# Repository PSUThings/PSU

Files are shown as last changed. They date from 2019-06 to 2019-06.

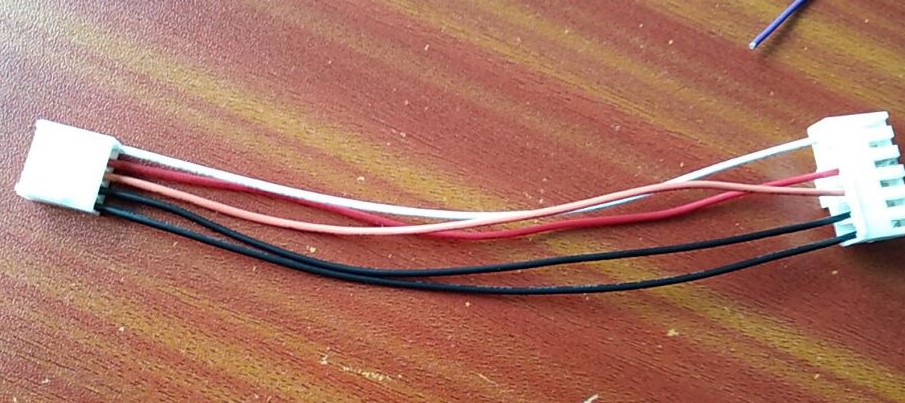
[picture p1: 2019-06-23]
Saturn/DesignFiles/TopMountCable.jpg

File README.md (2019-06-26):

Both designs work without issue on my end, BOM and Gerbers are there along with Eagle files.  
I have included as much info as i think you will need to get one of these up and running without issue.   
The rear adapters are stl files ready for 3d printing, the original design files i couldnt find, but shouldnt be needed.  
No licence, do what you want with the files.   

As suggested by someone, here is the links to oshpark. These should be easier for people who have no idea how to get a pcb made but can solder well. 

DreamPSU
https://oshpark.com/shared_projects/REVINxcE

SaturnPSU
https://oshpark.com/shared_projects/gURypobA

<!-- Now i have that out the way. Here is a little rant for you that checked this file. This shit is what represents just under 2 years of my life, I loved making the Dreamcast version of the psu cause it was new, fun and interesting, i learned so much from doing this, from eagle stuff to taking a labor of love to production and seeing peoples feedback. But the saturn version? I dont think there was one part of the experience that i enjoyed. Which sucks, i really wanted to do the saturn version cause of peoples constant asking for it, emails, tweets, facebook messages, all the time, so i was totally down to do it. But my god what a fucking shit show its turned out to be. From the mess that is saturn revisions to the fucking absolute disgrace that was the indiegogo campaign. There are god knows how many saturn revisions, which i had to try and source hardware for, which by the way is not an easy feat when your relying on ebay pictures to try and work out if you already own that version of the console, let alone the price of those things, most of which i brought non working or "untested", they cost me between £20-30 each, and i have no use for them after the final design was done. I dont play the saturn and when i did play it as a kid i wasnt a fan of it to be honest. My love was always the PS1 and the dreamcast. The fuck fest that happened with the campaign was nothing but a nightmare, from the first time the manafacturer screwed me over by increasing a quote by almost 30%, to issues with the cabling design for the top doown saturns and chinas inability to follow basic instructions, to the issues with fake or cloned TI chips. i couldnt beleive it. When i was oriignaly considering the saturn and wether or not i should go ahead and do a campaign for it (which by the way i had to, i know people are like "well what about the money you made from the dreampsu campaign", that dreampsu campaign left me damn near 2k in debt. so there was no money to put towards the saturn stuff besides a few intiial prototypes) i never would have dreamed it would turn out the way it did. I let myself down, everyone who help with the campaign down and everyone who made an order elsewhere down. That shit is not easy to handle when your as mentally fucked as i am lmao. And if your wondering, i dont care if i come across as weird or fucked up here, im drunk and im tired and pissed off, let me rant. Talking of ranting, its SOOOO hard to be nice to people all the time when they are berating you and trying to make you feel like shit (which btw guys, good luck cause i already feel as shit as its humanily possible), I do not envy people in customer service jobs.  OK im probably gonna leave this now before i start rambling, but i will say this, to anyone who has a neat idea or something that will help out the retro community, run at it with full force, make it the best thing you can possibly make it and then for the love of god dont try to sell it to anyone. Release that shit open source and never have to go though the same shit i have with this. I do want to say, once again to everyone that backed this thing, i am sorry from the bottom of my heart, this shit rips me apart every damn day knowing that you guys didnt get what u wanted. Hell i fear checking my phone or emails anytime it makes a noise though fear i have to face one of you again. I would also like to say thank you to everyone that was understanding of the sitation, everyone who offered help or guidance and advice, i cannot thank you enough, i dont want to mention people by names cause that aint fair, but you know who you are, even i replied to your email with not very much in the way of words, or didnt reply at all, i read every single email and bit of adcive you sent and i thank you for that.   Thats it from be folks, If at any point i decide to do another PSU for another console, i wont be selling them in any way shape or form, but i will make the files avaible for people as a further apology to everyone for all that has happened.  -->

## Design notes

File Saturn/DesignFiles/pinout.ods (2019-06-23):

Type A | GND | GND | 3.3V | 5v |  | 9v | TOP MOUNTED
Type B | GND | GND | 3.3V | 5v | 9v
Type C-5 | GND | GND | 5v | 5v | 12v
Type C-4 | GND | GND | 5v | 5v

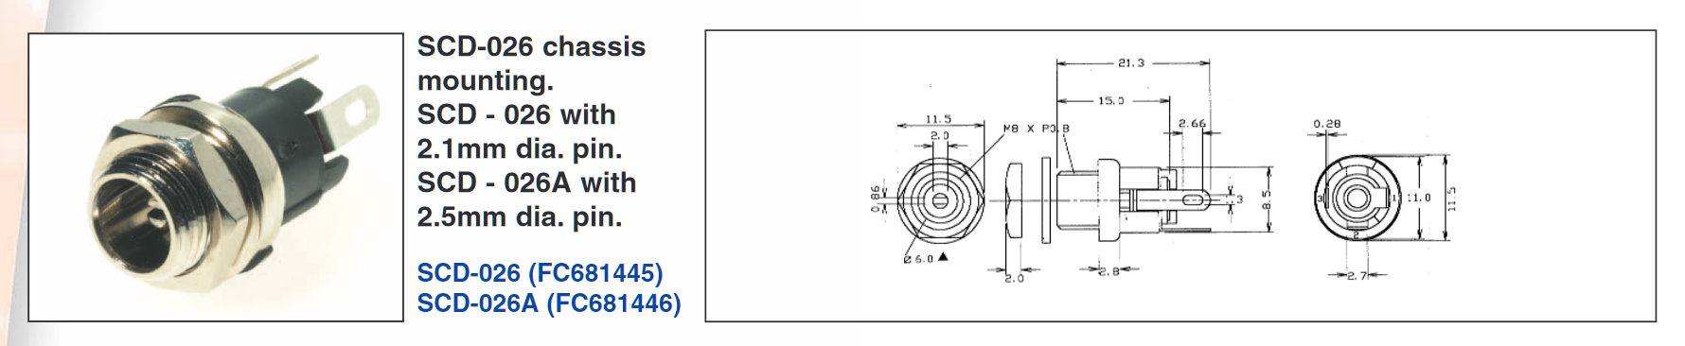
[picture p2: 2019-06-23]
Saturn/DesignFiles/Rear2.5MMJack - FC681446.png

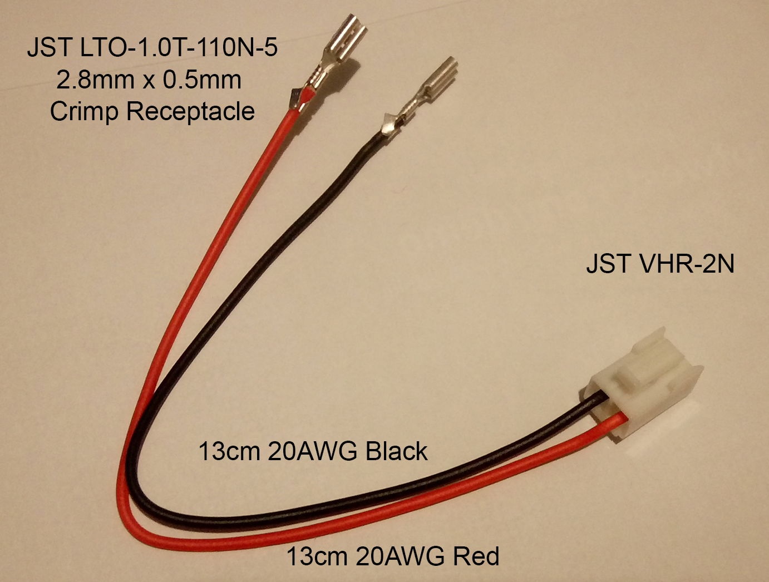
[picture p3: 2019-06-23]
Saturn/DesignFiles/Cable1.jpg

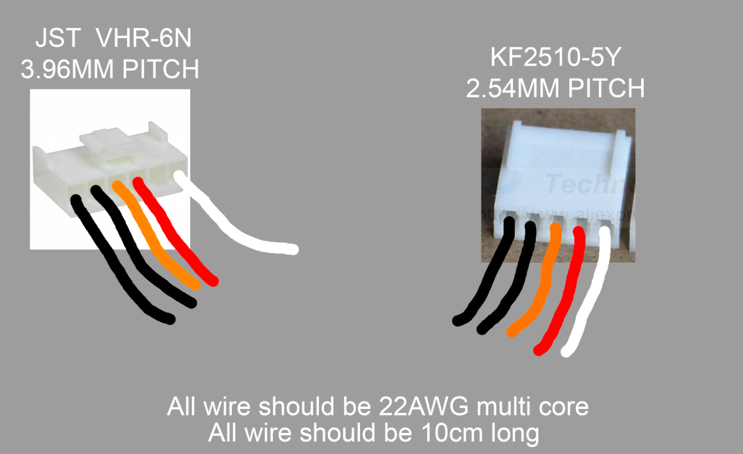
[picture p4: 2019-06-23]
Saturn/DesignFiles/xNnVytZ.png

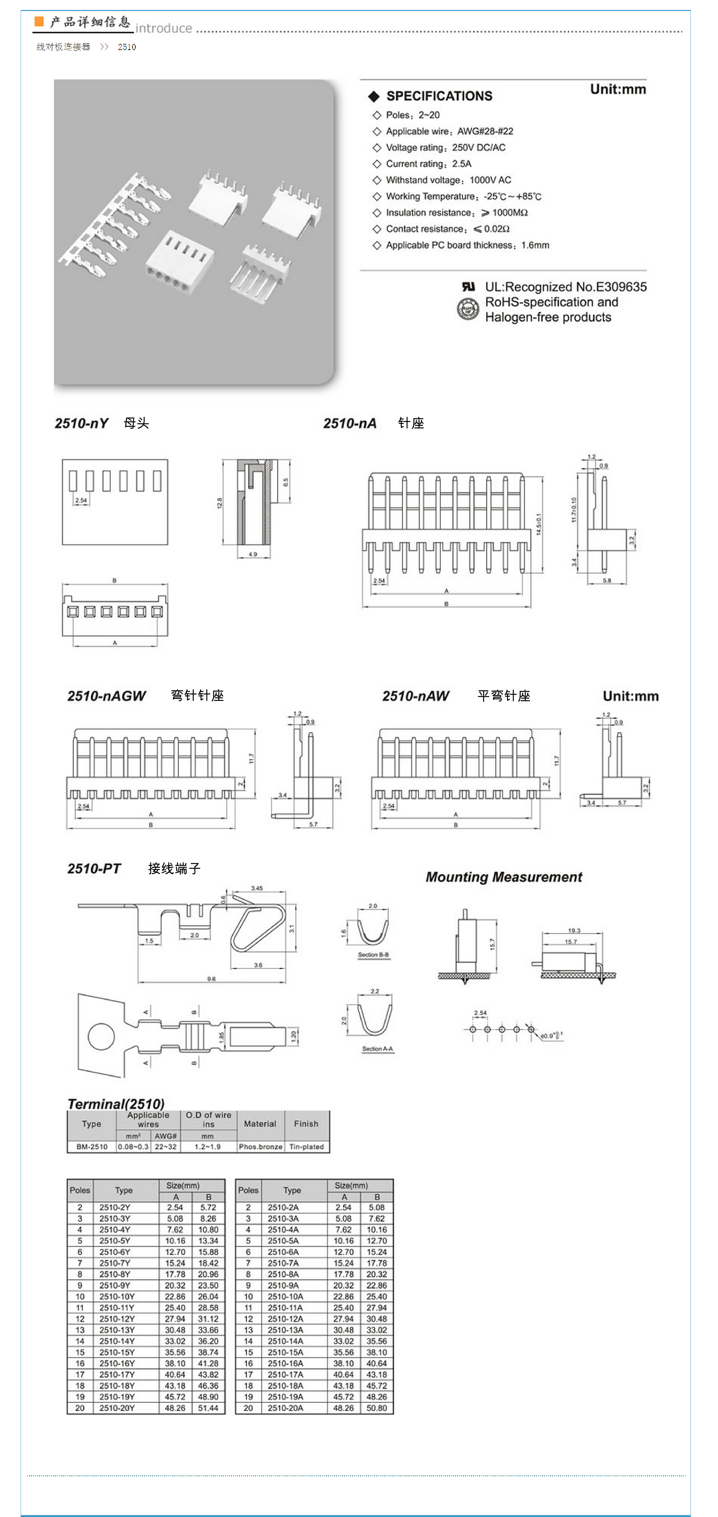
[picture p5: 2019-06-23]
Saturn/DesignFiles/KF2510-16A-2-54MM_C48201.png

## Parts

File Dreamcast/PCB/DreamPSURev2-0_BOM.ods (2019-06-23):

Ref | Value | Technology | Footprint | Manufacture | Manufacture Part Number | Quantity
R1,R6 | 10.2k,1%,1/10w | SMD | 0603 | Yageo | RC0603FR-0710K2L | 2
R4,R8 | 22.1k,1%,1/10w | SMD | 0603 | Yageo | RC0603FR-0722K1L | 2
R6 | 73.2k,1%,1/10w | SMD | 0603 | Yageo | RC0603FR-0773K2L | 1
R3,R7 | 100KΩ (1003) ±1% | SMD | 0603 | Yageo | 0603WAF1003T5E | 2
R2 | 124k,1%,1/10w | SMD | 0603 | Yageo | RC0603FR-07124KL | 1
C10,C2 | 100nF (104) ±10% 50V | SMD | 0603 | Yageo | CC0603KRX7R9BB104 | 2
C16,C8 | 1uF (105) ±10% 50V | SMD | 0603 | MuRata | CL10A105KB8NNNC | 2
C17,C9 | CAP CER 8200PF 50V X7R | SMD | 0603 | MuRata | GRM188R71H822KA01D | 2
C11,C3 | 10pF (100) ±5% 50V | SMD | 0603 | Kemet | CL10C100JB8NNNC | 2
C4,C5,C12,C13 | 10uF (106) ±10% 50V | SMD | 1206 | MuRata | CL31A106KBHNNNE | 4
C14,C15,C6,C7,C1 | 22uF (226) ±20% 25V | SMD | 0805 | Samsung | CL21A226MAQNNNE | 5
L2,L1 | Inductor 2.5uH | SMD | 7.60mm x 6.90mm | Pulse | PA4341.252NLT | 2
U1,U3 | IC REG BUCK ADJ 5.5A | SMD | 14-TSSOP | Texas Instruments | TPS54525PWPR | 2
JP3 | 2 Positions Header Right Angle Connector 3.96mm | THT | 7.92mm x 8.6mm | TE Connectivity | 647676-2 | 1
JP2 | 3 Positions Header Connector 7.92mm | THT | 11.9mm x 8.5mm | TE Connectivity | 1-1123724-2 | 1
JP1 | 6 Position, Bottom Entry Connector 3.96mm | THT | 23.7mm x 11.90mm | Molex | 0009523062 | 1
J1, J2, J3, J4 | 2 Positions Header Connector 2.54mm | THT | 1x2-2.5mm |  | 6030916A 1x2 Male | 4
 | REAR POWER JACK |  |  |  | FC681446 | 1

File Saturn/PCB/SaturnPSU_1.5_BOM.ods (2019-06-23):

Ref | Value | Technology | Footprint | Manufacture | Manufacture Part Number | Quantity
R11,R5 | 10.2k,1%,1/10w | SMD | 0603 | Yageo | RC0603FR-0710K2L | 2
R9 | 22.1k,1%,1/10w | SMD | 0603 | Yageo | RC0603FR-0722K1L | 1
R12 | 100KΩ (1003) ±1% | SMD | 0603 | Yageo | 0603WAF1003T5E | 1
R10 | 124k,1%,1/10w | SMD | 0603 | Yageo | RC0603FR-07124KL | 1
R6 | 33.2k,1%,1/10w | SMD | 0603 | Yageo | RC0603FR-0733K2L | 1
R1 | 54.9k,1%,1/10w | SMD | 0603 | Yageo | RC0603FR-0754K9L | 1
C17 | 47µF ±20% 6.3V 1206 | SMD | 1206 | Samsung Electro-Mechanics | CL31A476MQHNNWE | 1
C2,C16,C23 | 100nF (104) ±10% 50V | SMD | 0603 | Yageo | CC0603KRX7R9BB104 | 3
C1,C21 | 1uF (105) ±10% 50V | SMD | 0603 | MuRata | CL10A105KB8NNNC | 2
C22 | CAP CER 8200PF 50V X7R | SMD | 0603 | MuRata | GRM188R71H822KA01D | 1
C9 | 10pF (100) ±5% 50V | SMD | 0603 | Kemet | CL10C100JB8NNNC | 1
C19,C20 | 10uF (106) ±10% 50V | SMD | 1206 | MuRata | CL31A106KBHNNNE | 2
C10,C15,C18,C24 | 22uF (226) ±20% 25V | SMD | 0805 | Samsung | CL21A226MAQNNNE | 4
L2,L3 | Inductor 2.5uH | SMD | 7.60mm x 6.90mm | Pulse | PA4341.252NLT | 2
U6 | Buck Switching Regulator | SMD | TSOT-23-6 | Texas Instruments | TPS563200 | 1
U2 | IC REG BUCK ADJ 5.5A | SMD | 14-TSSOP | Texas Instruments | TPS54525PWPR | 1
U5 | Linear Voltage Regulator | SMD | SOT-89-3 | STMicroelectronics | L78L09ABUTR | 1
SW1 | Slide Switch SPDT Surface Mount, Right Angle | SMD | 8mmx6mm | C&K | AYZ0102AGRLC | 1
JP5 | 2 Positions Header Right Angle Connector 3.96mm | THT | 7.92mm x 8.6mm | TE Connectivity | 647676-2 | 1
JP4 | 3 Positions Header Connector 7.92mm | THT | 11.9mm x 8.5mm | TE Connectivity | 1-1123724-2 | 1
J5,J6,J7 | 2 Positions Header Connector 2.54mm | THT | 1x2-2.5mm |  | 6030916A 1x2 Male | 3
J1 | 5 Positions Header Connector 2.54mm | THT | 1x5-2.54mm |  | KF2510-5A-2.54MM | 1
JP1 | 5 Position, Bottom Entry Connector 3.96mm | THT | 20.85mm x 11.90mm | Molex | 09-48-4059 | 1
 | REAR POWER JACK |  |  |  | FC681446 | 1

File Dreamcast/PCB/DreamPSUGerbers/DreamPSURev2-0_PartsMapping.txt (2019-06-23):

Partlist

Exported from DreamPSURev2-0.brd at 12/03/2018 16:44

EAGLE Version 8.4.3 Copyright (c) 1988-2017 Autodesk, Inc.

Assembly variant: 

Part     Value                       Package                     Library        Position (mm)         Orientation

C1       22uF                        C0805                       DreamPSURev1-9 (39.9 1.84)           R0
C2       100nF                       C0603                       DreamPSURev1-9 (33.2 21.64)          R270
C3       10pF                        C0603                       DreamPSURev1-9 (37 33.04)            R180
C4       10uF                        C1206                       DreamPSURev1-9 (38.8 26.14)          R270
C5       10uF                        C1206                       DreamPSURev1-9 (36.4 26.14)          R270
C6       22uF                        C0805                       DreamPSURev1-9 (34.7 13.99)          R180
C7       22uF                        C0805                       DreamPSURev1-9 (34.7 16.49)          R180
C8       1uF                         C0603                       DreamPSURev1-9 (30.2 35.74)          R90
C9       8.2nF                       C0603                       DreamPSURev1-9 (32.3 35.74)          R90
C10      100nF                       C0603                       DreamPSURev1-9 (12.509 10.385)       R270
C11      10pF                        C0603                       DreamPSURev1-9 (16.42 21.62)         R180
C12      10uF                        C1206                       DreamPSURev1-9 (18.85 13.9)          R270
C13      10uF                        C1206                       DreamPSURev1-9 (16.28 13.93)         R270
C14      22uF                        C0805                       DreamPSURev1-9 (18.7291 2.9035)      R90
C15      22uF                        C0805                       DreamPSURev1-9 (15.8 2.89)           R90
C16      1uF                         C0603                       DreamPSURev1-9 (9.6 24.54)           R90
C17      8.2nF                       C0603                       DreamPSURev1-9 (11.7 24.54)          R90
J1       5V                          10X02MTA                    DreamPSURev1-9 (44 29)               R90
J2       12V                         10X02MTA                    DreamPSURev1-9 (44 22.5)             R90
J3       5V                          10X02MTA                    DreamPSURev1-9 (44 35.5)             R90
J4       12V                         10X02MTA                    DreamPSURev1-9 (44 16)               R90
JP1      09-48-3064                  09-62-3062                  DreamPSURev1-9 (33.44 8.32)          R0
JP2      DC-PWRSW                    1-1123724-2                 SaturnPSU_1.5  (7.786 35.823)        R180
JP3      640445-2_3.96MM-2PIN-HEADER 640445-2_3.96MM-2PIN-HEADER SaturnPSU_1.5  (19.6 35.94)          R180
L1       2.5uH                       PA4341.252NLT               SaturnPSU_1.5  (28 19.04)            R0
L2       2.5uH                       PA4341.252NLT               SaturnPSU_1.5  (6.5 8.2)             R0
R1       10.2k                       R0603                       DreamPSURev1-9 (27.8 32.44)          R180
R2       124k                        R0603                       DreamPSURev1-9 (37 35.14)            R0
R3       100k                        R0603                       DreamPSURev1-9 (28.1 35.74)          R90
R4       22.1k                       R0603                       DreamPSURev1-9 (34.4 35.74)          R270
R5       10.2k                       R0603                       DreamPSURev1-9 (7.508 20.657)        R180
R6       73.2k                       R0603                       DreamPSURev1-9 (16.43 23.739)        R0
R7       100k                        R0603                       DreamPSURev1-9 (7.5 24.54)           R90
R8       22.1k                       R0603                       DreamPSURev1-9 (13.8 24.54)          R270
TP1      TPSQB1,27                   B1,27                       DreamPSURev1-9 (27.49 1.99)          R0
TP2      TPSQB1,27                   B1,27                       DreamPSURev1-9 (31.47 2)             R0
TP3      TPSQB1,27                   B1,27                       DreamPSURev1-9 (23.5352 1.9785)      R0
TP4      TPSQB1,27                   B1,27                       DreamPSURev1-9 (43.37 1.99)          R0
TP5      TPSQB1,27                   B1,27                       DreamPSURev1-9 (35.43 2.05)          R0
U1       TPS54525PWPR                R-PDSO-G14                  DreamPSURev1-9 (32.3 28.24)          R270
U3       TPS54525PWPR                R-PDSO-G14                  DreamPSURev1-9 (11.71 16.54)         R270

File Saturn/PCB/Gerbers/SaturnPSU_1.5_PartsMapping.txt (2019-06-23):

Partlist

Exported from SaturnPSU_1.5.brd at 12/03/2018 15:52

EAGLE Version 8.4.3 Copyright (c) 1988-2017 Autodesk, Inc.

Assembly variant: 

Part     Value                       Package                     Library        Position (mm)         Orientation

C1       1uF                         C0603                       DreamPSURev1-9 (11.6 6.8)            R0
C2       100nF                       C0603                       DreamPSURev1-9 (10.6 14.6)           R180
C9       10pF                        C0603                       DreamPSURev1-9 (7.58 39.97)          R270
C10      22uF                        C0805                       DreamPSURev1-9 (23.8 14.6)           R90
C15      22uF                        C0805                       DreamPSURev1-9 (17.3 9.6)            R90
C16      100nF                       C0603                       DreamPSURev1-9 (24 7.1)              R0
C17      47uF                        C1206                       resistor       (38.9 5.9)            R180
C18      22uF                        C0805                       DreamPSURev1-9 (21.1 14.6)           R90
C19      10uF                        C1206                       DreamPSURev1-9 (15.3 42.2)           R0
C20      10uF                        C1206                       DreamPSURev1-9 (15.27 39.63)         R0
C21      1uF                         C0603                       DreamPSURev1-9 (4.66 33.15)          R180
C22      8.2nF                       C0603                       DreamPSURev1-9 (4.66 35.25)          R180
C23      100nF                       C0603                       DreamPSURev1-9 (18.815 36.059)       R0
C24      22uF                        C0805                       DreamPSURev1-9 (18.5 14.6)           R90
J1       9v                          KF2510-5A-2.54MM            SaturnPSU_1.5  (39.1 15.5)           R90
J5       5V                          6030916A                    SaturnPSU_1.4  (25.5 37.8)           R90
J6       12V                         6030916A                    SaturnPSU_1.4  (33.7 37.8)           R270
J7       5V                          6030916A                    SaturnPSU_1.4  (30 37.8)             R90
JP1      MOLEX-5PIN-09-48-3054       09-48-3054                  SaturnPSU_1.5  (25.785 21.865)       R0
JP4      DC-PWRSW                    1-1123724-2                 SaturnPSU_1.5  (4.277 9.636)         R270
JP5      640445-2_3.96MM-2PIN-HEADER 640445-2_3.96MM-2PIN-HEADER SaturnPSU_1.4  (6.76 21.55)          R270
L2       2.5uH                       PA4341.252NLT               SaturnPSU_1.5  (30.1 8.3)            R90
L3       2.5uH                       PA4341.252NLT               SaturnPSU_1.4  (21.26 30.35)         R90
R1       54.9k                       R0603                       DreamPSURev1-9 (14.6 6.1)            R90
R5       10.2k                       R0603                       DreamPSURev1-9 (17.6 6.4)            R180
R6       33.2k                       R0603                       DreamPSURev1-9 (24 5)                R0
R9       22.1k                       R0603                       DreamPSURev1-9 (4.66 37.35)          R0
R10      124k                        R0603                       DreamPSURev1-9 (5.461 39.98)         R90
R11      10.2k                       R0603                       DreamPSURev1-9 (8.543 31.058)        R270
R12      100k                        R0603                       DreamPSURev1-9 (4.66 31.05)          R180
SW1      AYZ0102AGRLC                AYZ0102AGRLC                SaturnPSU_1.5  (18.6 3.9)            R0
U2       TPS54525PWPR                R-PDSO-G14                  DreamPSURev1-9 (12.66 35.26)         R0
U5       L78L09ABUTR                 SOT-89                      SaturnPSU_1.5  (11.7 10.5)           R270
U6       TPS563200DDCR               DDC0006A                    SaturnPSU_1.5  (20.8 8.6)            R270

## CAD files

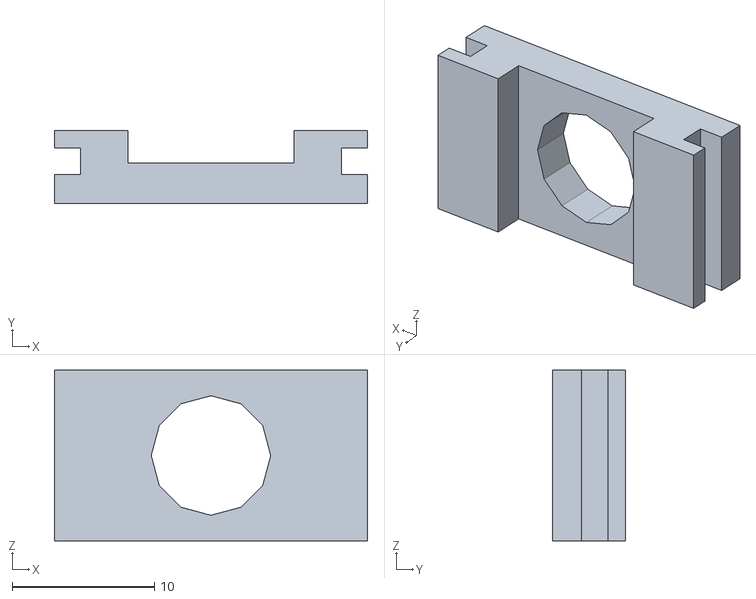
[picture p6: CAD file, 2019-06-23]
Dreamcast/DesignFiles/DreamPSU_Jack_Final.stl
22.0 x 5.11 x 12.0

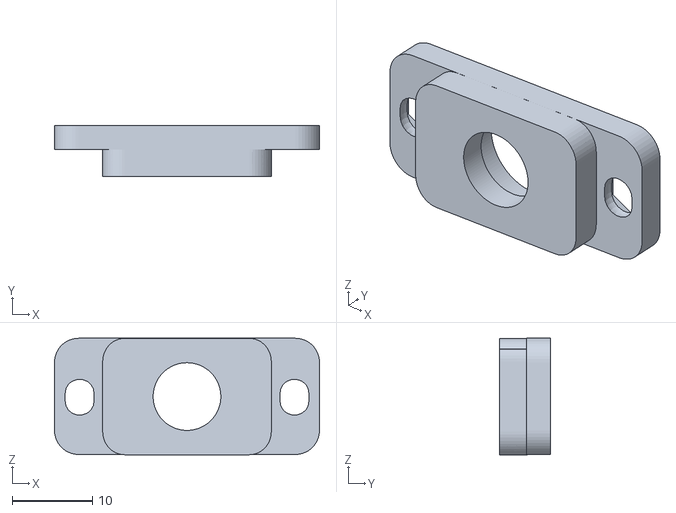
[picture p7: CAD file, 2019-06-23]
Saturn/DesignFiles/RearAdapter/SaturnPSU_B.stl
33.0 x 6.38 x 14.5

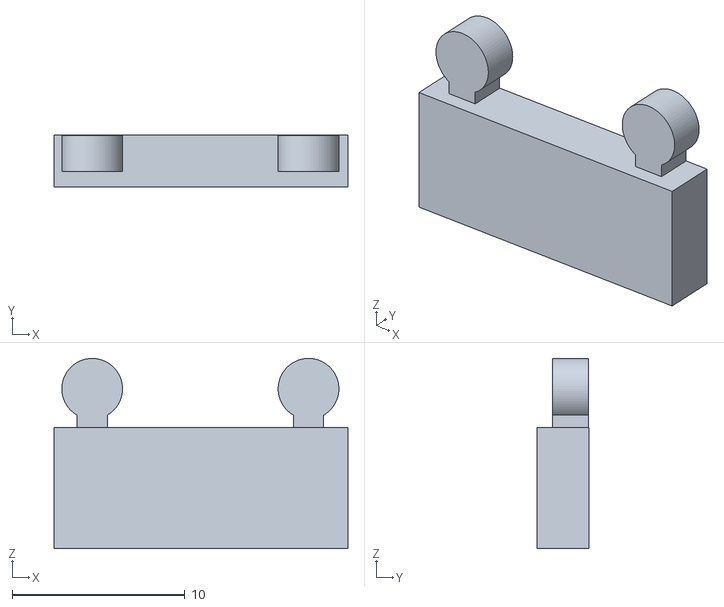
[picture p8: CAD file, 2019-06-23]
Saturn/DesignFiles/RearAdapter/SaturnPSU_A.stl
17.0 x 3.00 x 11.0

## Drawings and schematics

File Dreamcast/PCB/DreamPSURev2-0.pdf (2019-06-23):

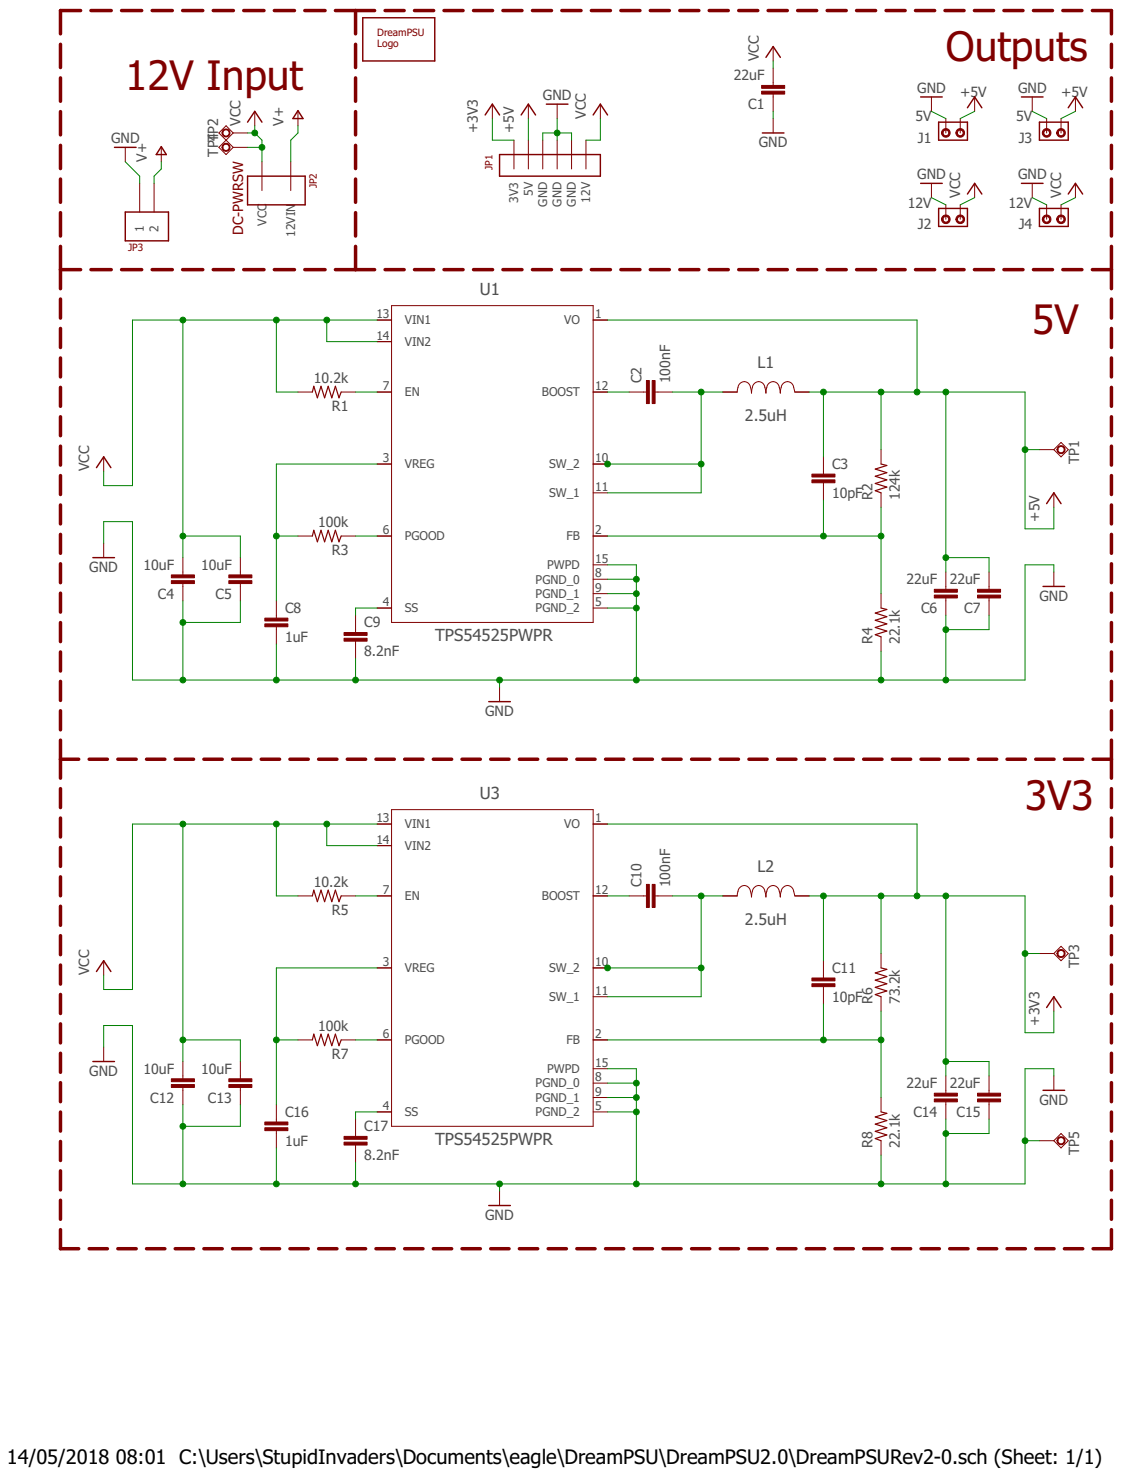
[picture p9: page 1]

14/05/2018 08:01 C:\Users\StupidInvaders\Documents\eagle\DreamPSU\DreamPSU2.0\DreamPSURev2-0.sch (Sheet: 1/1)

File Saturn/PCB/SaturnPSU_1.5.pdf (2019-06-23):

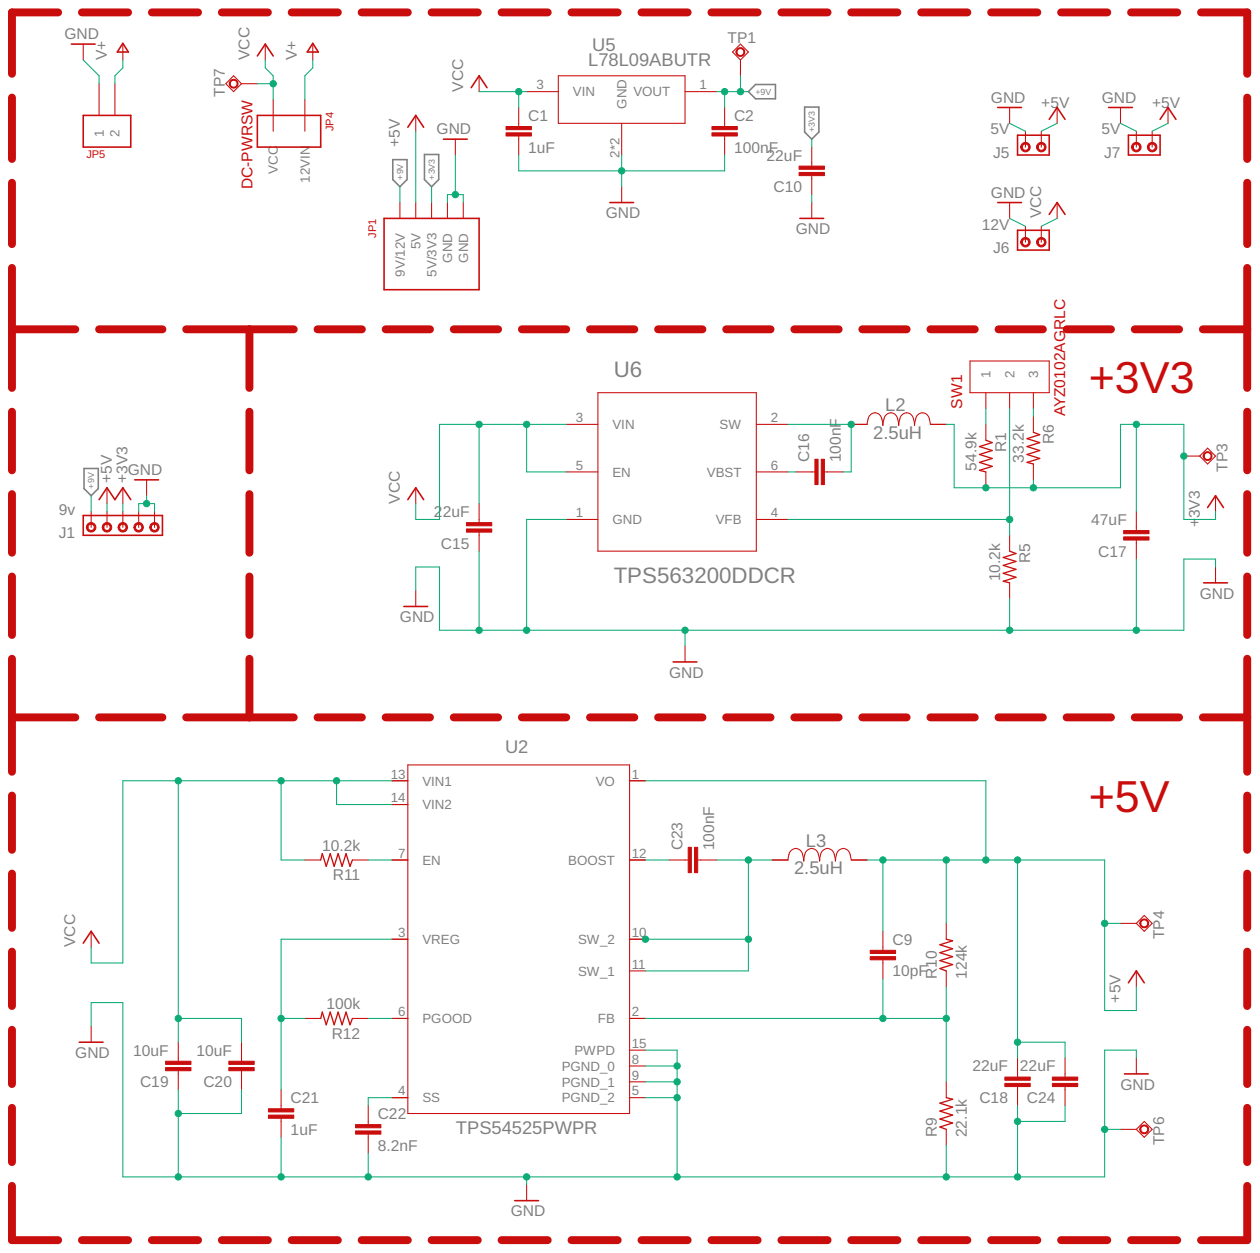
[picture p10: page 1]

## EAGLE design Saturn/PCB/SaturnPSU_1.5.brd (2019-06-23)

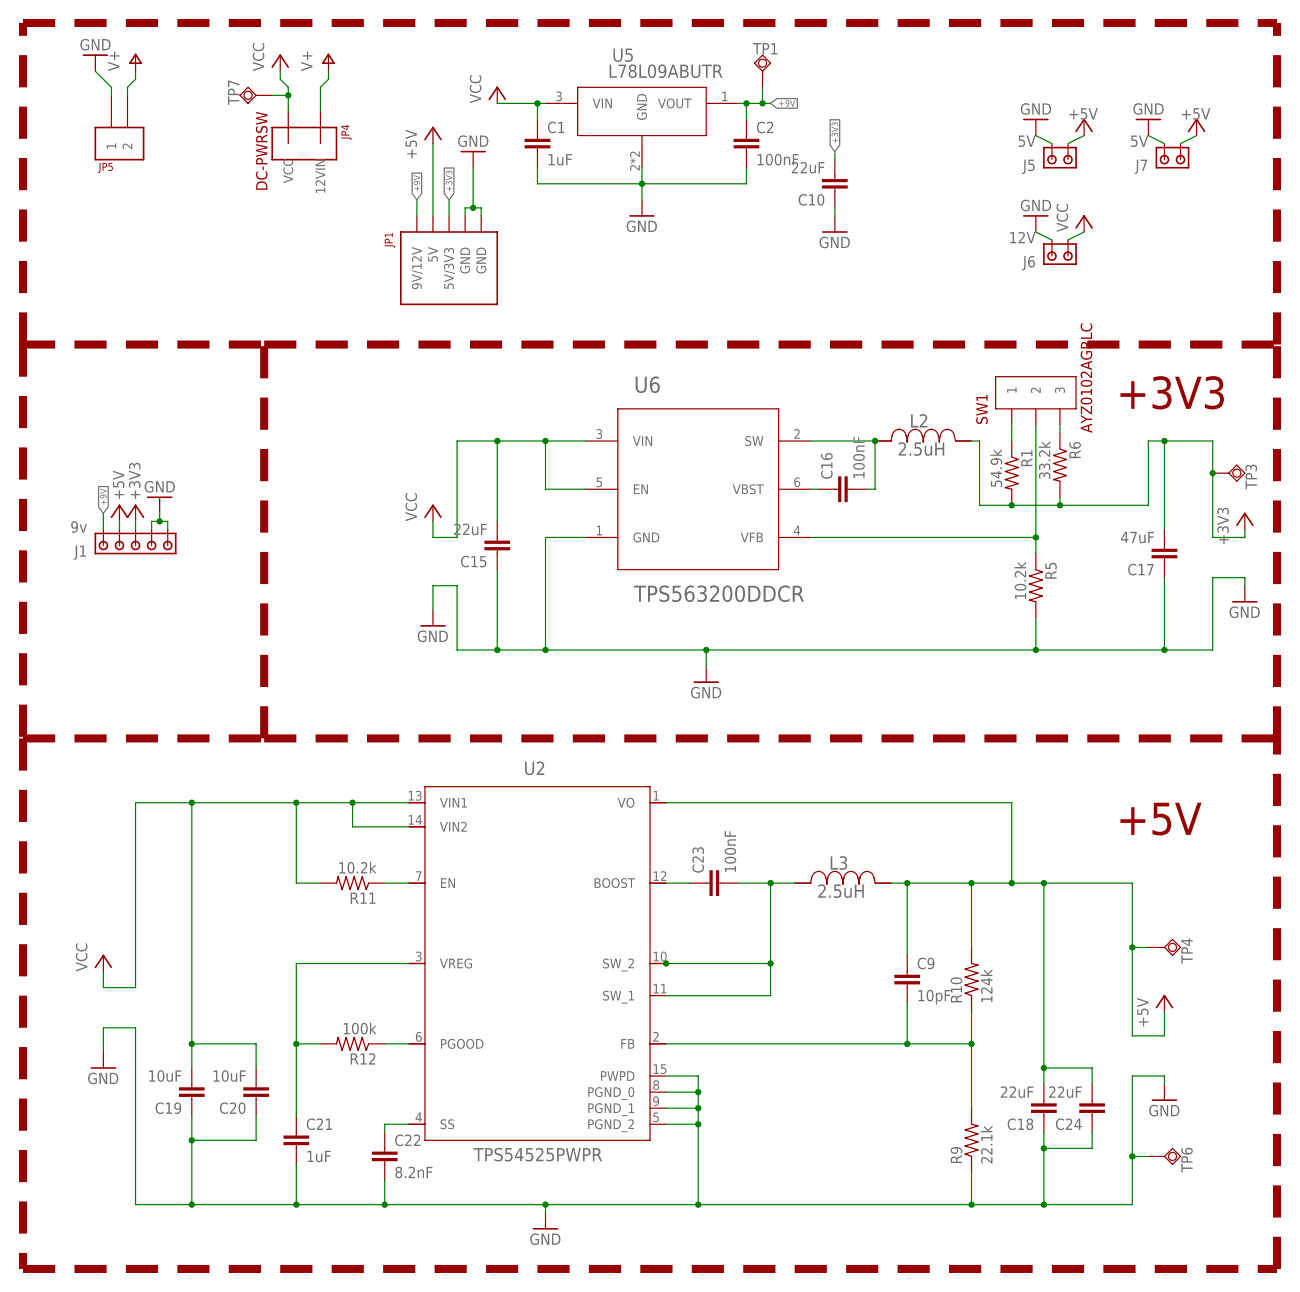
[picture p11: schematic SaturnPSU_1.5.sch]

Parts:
C1, C21: 1uF; C0603
C2, C16, C23: 100nF; C0603
C9: 10pF; C0603
C10, C15, C18, C24: 22uF; C0805
C17: 47uF; C1206
C19, C20: 10uF; C1206
C22: 8.2nF; C0603
J1: 9v; KF2510-5A-2.54MM
J5, J7: 5V; 6030916A
J6: 12V; 6030916A
JP1: MOLEX-5PIN-09-48-3054; 09-48-3054
JP4: DC-PWRSW; 1-1123724-2
JP5: 640445-2_3.96MM-2PIN-HEADER
L2, L3: 2.5uH; PA4341.252NLT
R1: 54.9k; R0603
R5, R11: 10.2k; R0603
R6: 33.2k; R0603
R9: 22.1k; R0603
R10: 124k; R0603
R12: 100k; R0603
SW1: AYZ0102AGRLC
TP1, TP3, TP4, TP6, TP7: TPSQB1,27; B1,27
U2: TPS54525PWPR; R-PDSO-G14
U5: L78L09ABUTR; SOT-89
U6: TPS563200DDCR; DDC0006A

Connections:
2: C23.2, L3.P$1 (1), U2.10 (SW_2), U2.11 (SW_1)
+3V3: C10.2, C17.2, J1.3, JP1.3 (5V/3V3), L2.P$2 (2), R1.2, R6.2, TP3.TP
+5V: C9.1, C18.2, C24.2, J1.4, J5.POWER, J7.POWER, JP1.4 (5V), L3.P$2 (2), R10.2, TP4.TP, U2.1 (VO)
+9V: C2.1, J1.5, JP1.5 (9V/12V), TP1.TP, U5.1 (VOUT)
GND: C1.2, C2.2, C10.1, C15.1, C17.1, C18.1, C19.1, C20.1, C21.2, C22.2, C24.1, J1.1, J1.2, J5.GND, J6.GND, J7.GND, JP1.1 (GND), JP1.2 (GND), JP5.P$1 (1), R5.2, R9.1, TP6.TP, U2.5 (PGND_2), U2.8 (PGND_0), U2.9 (PGND_1), U2.15 (PWPD), U5.2 (GND), U5.P$1 (GND), U6.1 (GND)
unnamed: R1.1, SW1.1
unnamed: R6.1, SW1.3
unnamed: C16.2, L2.P$1 (1), U6.2 (SW)
unnamed: C16.1, U6.6 (VBST)
unnamed: R5.1, SW1.2, U6.4 (VFB)
unnamed: R11.1, U2.7 (EN)
unnamed: C21.1, R12.2, U2.3 (VREG)
unnamed: R12.1, U2.6 (PGOOD)
unnamed: C22.1, U2.4 (SS)
unnamed: C9.2, R9.2, R10.1, U2.2 (FB)
unnamed: C23.1, U2.12 (BOOST)
V+: JP4.12VIN, JP5.P$2 (2)
VCC: C1.1, C15.2, C19.2, C20.2, J6.POWER, JP4.VCC, R11.2, TP7.TP, U2.13 (VIN1), U2.14 (VIN2), U5.3 (VIN), U6.3 (VIN), U6.5 (EN)

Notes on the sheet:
+3V3
+5V

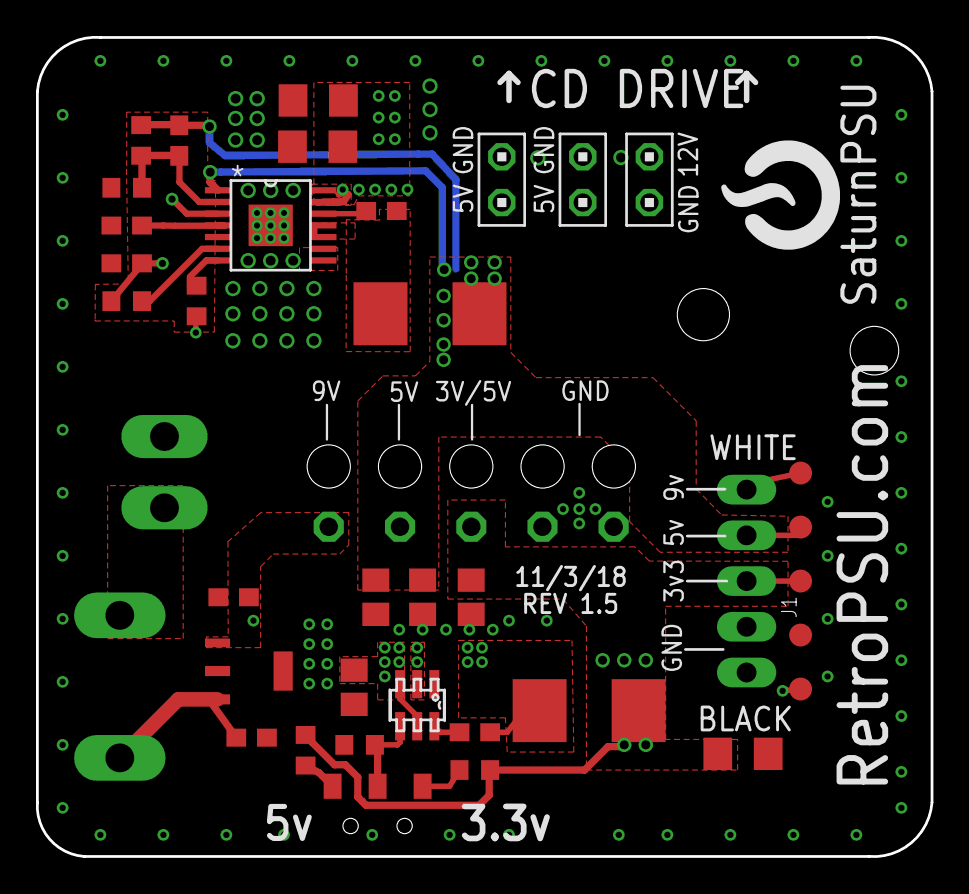
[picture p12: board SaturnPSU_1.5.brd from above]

Board: 4 copper layers, 49.7 x 45.5 mm, 39 parts (0 on the bottom side), 18 nets.

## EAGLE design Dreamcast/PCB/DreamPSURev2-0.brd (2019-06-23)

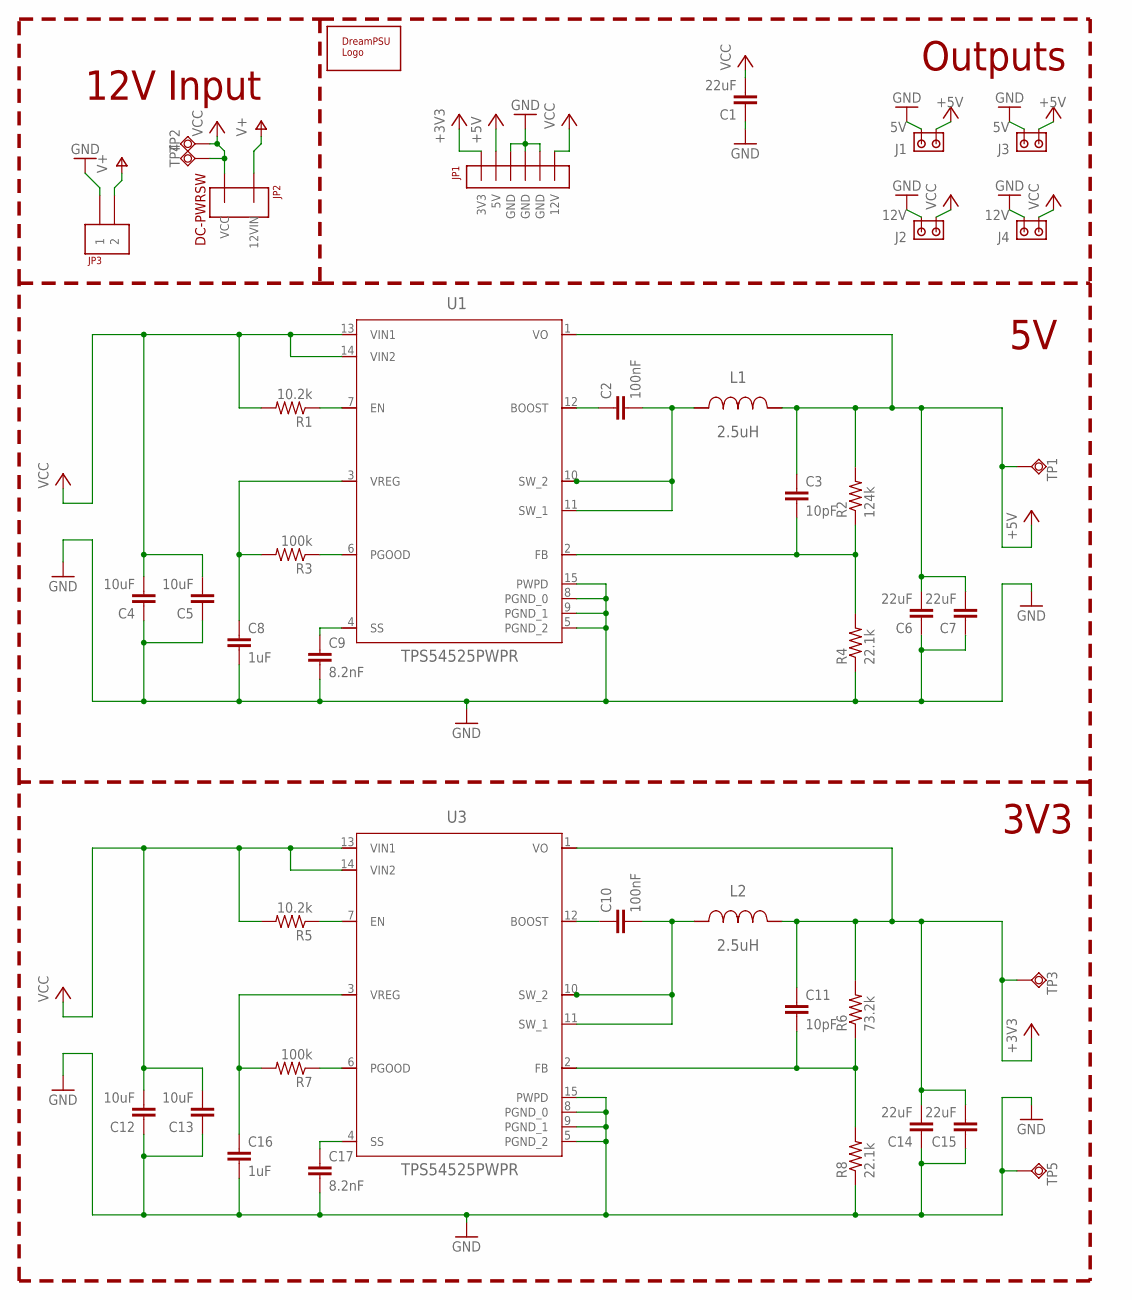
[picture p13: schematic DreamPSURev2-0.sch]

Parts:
C1, C6, C7, C14, C15: 22uF; C0805
C2, C10: 100nF; C0603
C3, C11: 10pF; C0603
C4, C5, C12, C13: 10uF; C1206
C8, C16: 1uF; C0603
C9, C17: 8.2nF; C0603
J1, J3: 5V; 10X02MTA
J2, J4: 12V; 10X02MTA
JP1: 09-48-3064; 09-62-3062
JP2: DC-PWRSW; 1-1123724-2
JP3: 640445-2_3.96MM-2PIN-HEADER
L1, L2: 2.5uH; PA4341.252NLT
R1, R5: 10.2k; R0603
R2: 124k; R0603
R3, R7: 100k; R0603
R4, R8: 22.1k; R0603
R6: 73.2k; R0603
TP1, TP2, TP3, TP4, TP5: TPSQB1,27; B1,27
U1, U3: TPS54525PWPR; R-PDSO-G14
U$3: DREAMPSU

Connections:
2: C2.2, L1.P$1 (1), U1.10 (SW_2), U1.11 (SW_1)
18: C10.2, L2.P$1 (1), U3.10 (SW_2), U3.11 (SW_1)
+3V3: C11.1, C14.2, C15.2, JP1.3V3, L2.P$2 (2), R6.2, TP3.TP, U3.1 (VO)
+5V: C3.1, C6.2, C7.2, J1.POWER, J3.POWER, JP1.5V, L1.P$2 (2), R2.2, TP1.TP, U1.1 (VO)
GND: C1.1, C4.1, C5.1, C6.1, C7.1, C8.2, C9.2, C12.1, C13.1, C14.1, C15.1, C16.2, C17.2, J1.GND, J2.GND, J3.GND, J4.GND, JP1.GND@0 (GND), JP1.GND@1 (GND), JP1.GND@2 (GND), JP3.P$1 (1), R4.1, R8.1, TP5.TP, U1.5 (PGND_2), U1.8 (PGND_0), U1.9 (PGND_1), U1.15 (PWPD), U3.5 (PGND_2), U3.8 (PGND_0), U3.9 (PGND_1), U3.15 (PWPD)
unnamed: R1.1, U1.7 (EN)
unnamed: C8.1, R3.2, U1.3 (VREG)
unnamed: R5.1, U3.7 (EN)
unnamed: C10.1, U3.12 (BOOST)
unnamed: R3.1, U1.6 (PGOOD)
unnamed: C9.1, U1.4 (SS)
unnamed: C16.1, R7.2, U3.3 (VREG)
unnamed: R7.1, U3.6 (PGOOD)
unnamed: C17.1, U3.4 (SS)
unnamed: C11.2, R6.1, R8.2, U3.2 (FB)
unnamed: C3.2, R2.1, R4.2, U1.2 (FB)
unnamed: C2.1, U1.12 (BOOST)
V+: JP2.12VIN, JP3.P$2 (2)
VCC: C1.2, C4.2, C5.2, C12.2, C13.2, J2.POWER, J4.POWER, JP1.12V, JP2.VCC, R1.2, R5.2, TP2.TP, TP4.TP, U1.13 (VIN1), U1.14 (VIN2), U3.13 (VIN1), U3.14 (VIN2)

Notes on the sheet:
3V3
Outputs
12V Input

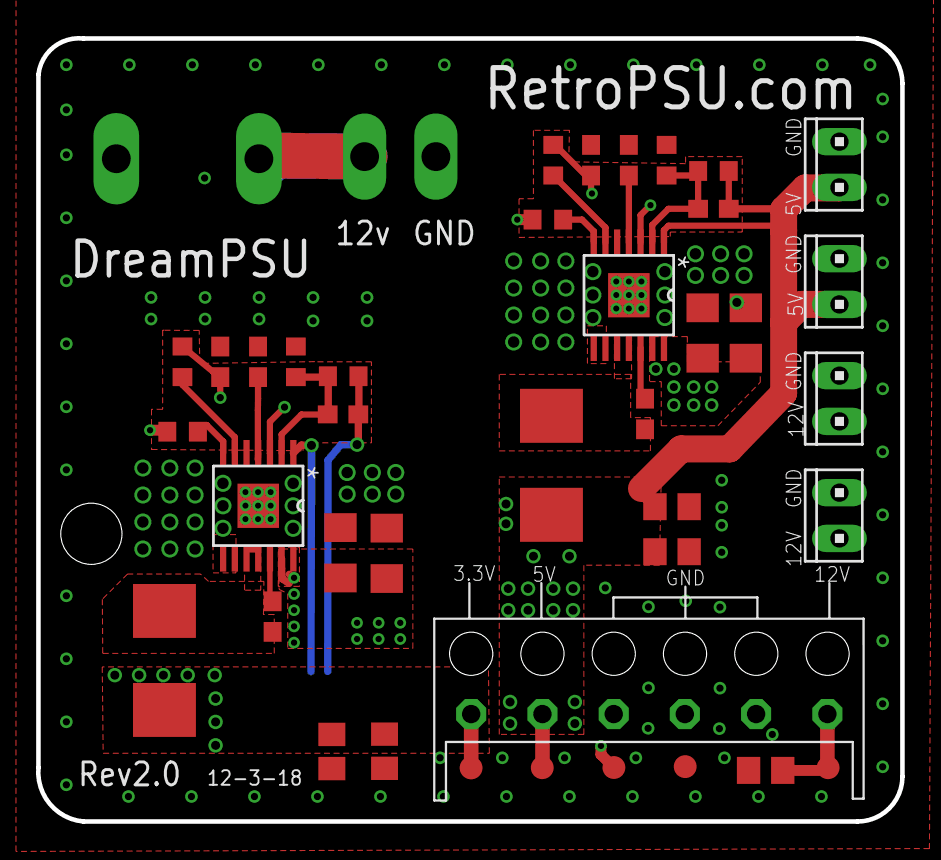
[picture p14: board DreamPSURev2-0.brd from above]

Board: 4 copper layers, 48.0 x 43.5 mm, 42 parts (1 on the bottom side), 19 nets.

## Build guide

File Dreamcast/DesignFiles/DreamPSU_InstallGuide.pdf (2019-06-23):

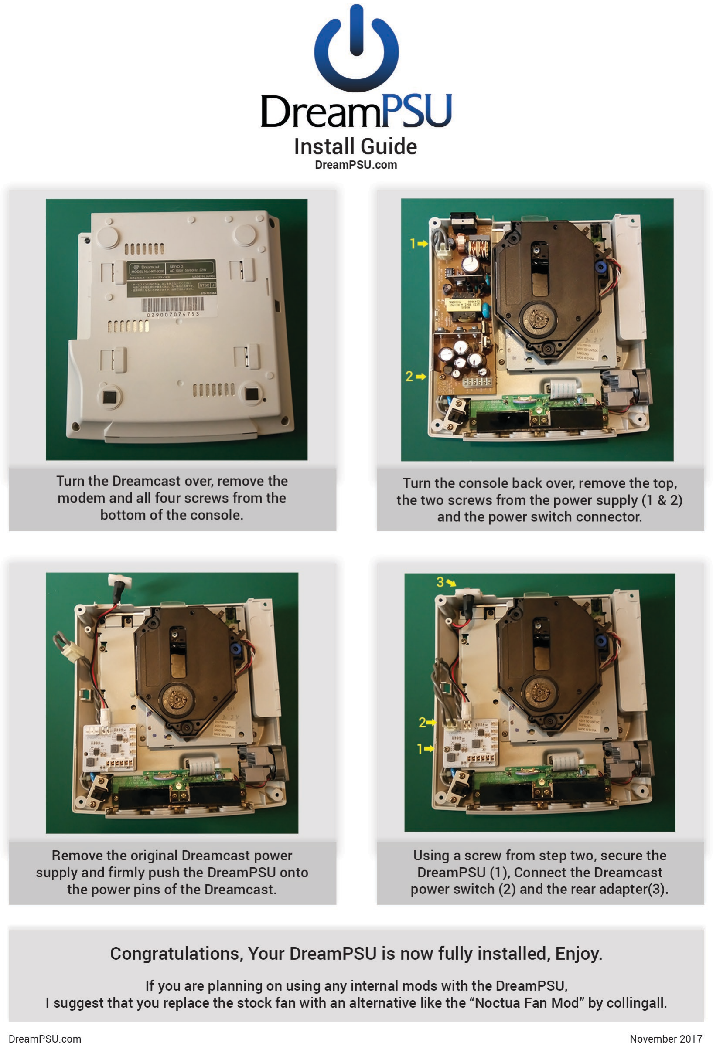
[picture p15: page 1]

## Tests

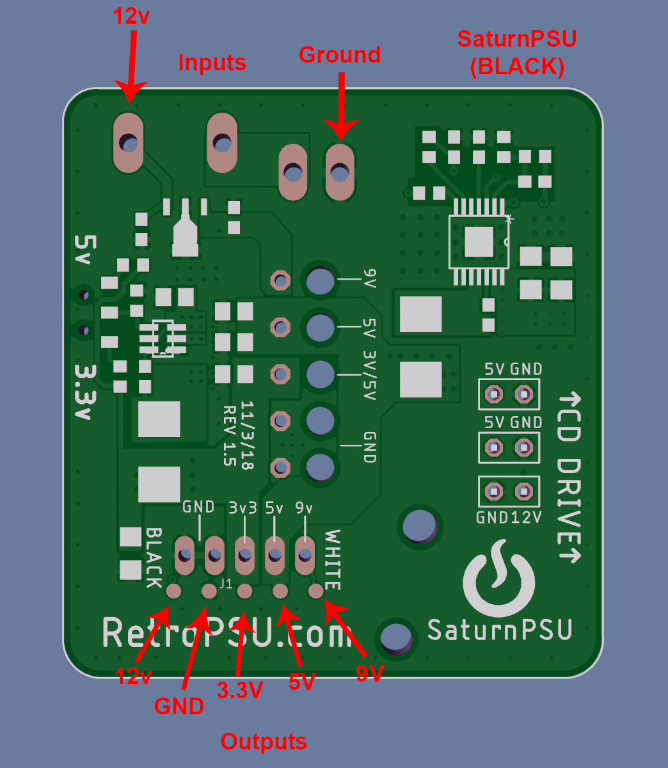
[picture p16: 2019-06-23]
Saturn/DesignFiles/SaturnPSU_Test.png
